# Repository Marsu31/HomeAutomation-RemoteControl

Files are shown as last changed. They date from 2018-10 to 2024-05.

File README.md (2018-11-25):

# HomeAutomation-RemoteControl
MQTT Wifi/BLE Remote control

## Besoin

### Problématique

Les volets roulants électriques sont équipés de modules domotique et s'ouvrent automatiquement au lever du soleil. Pour ce qui est de leur fermeture, le soir, chaque jour est une sitation différente assez imprédictible. L'idée est donc de pouvoir agir avec un moyen simple tel l'appui sur un bouton.
Un bouton 1-Click aurait pu faire l'affaire mais ne présente aucune évolutivité. Une télécommande plus complète permet aussi de se challenger ^^

### Cahier des charges

* **Pratique**
 * **Tenir dans la main**. Pas dans 2 mains, pas dans une main de géant.
 * **Actions rapides**. Par simple appui sur un bouton.
 * **Configurable**. Pour évoluer avec l'équipement de la maison et les besoins qui apparaîtront avec le temps. La saisie doit être ergonomique.
 * **Rechargeable**. Puisque sans fil. Pas sûr que ce soit super écolo mais j'apprendrai ainsi à gérer une batterie.
 * **Sans fil**. Ca semble évident.
 * **Lisible**. Ecran LCD, en relation avec la configurabilité.
 * **Utilisable dès la prise en main**. Ne pas attendre une sortie de veille trop longue.
* **Compatible**. Afin d'être utilisable avec un maximum de systèmes domotiques si jamais nous devions en changer.
* **Consommation réduite**. Pour le &laquo; léger &raquo; côté écolo.

## Conception

### Spécifications techniques

* **Tenir dans la main** : après mesure d'une main on obtient les dimensions L x l x h = 120 x 60 x 40 mm. Il faudrait que l'ensemble rentre dans ce volume.
* **Actions rapides** : 4 boutons poussoir aux couleurs habituelles sur les radiocommandes (rouge, vert, jaune, bleu).
* **Configurable** : encodeur rotatif avec interrupteur afin de naviguer aisément dans un menu, défilement des items sur l'écran LCD.
* **Rechargeable** : via la prise USB du module ESP.
* **Sans fil** : utilisation d'un ESP8266 ou ESP32 pour le Wifi voire le BLE.
* **Lisible** : écran LCD de 1,8".
* **Utilisable dès la prise en main** : capteur de secousse pour la détection.
* **Compatible** : protocole MQTT.
* **Consommation réduite** : mise en veille d'un maximum de composants (ESP, écran).

Utilisation des logiciels suivants :
* conception 3D : FreeCAD
* conception PCB : Fritzing + KiCAD
* préparation de l'impression 3D : Cura

### Maquette

La première étape consiste en la modélisation du volume. Une forme ovoïde semble facile à tenir.

L'écran, l'encodeur, les boutons et le module ESP ont des tailles bien déterminées. Commençons par les positionner.

Ensuite on peut chercher des composants adaptés à l'espace restant. Le plus volumineux d'entre eux est la batterie LiPo. 10 batteries sont étudiées, le modèle de 1200 mAh rentre convenablement sans déborder.

Voici l'esquisse résultant de cette étude :
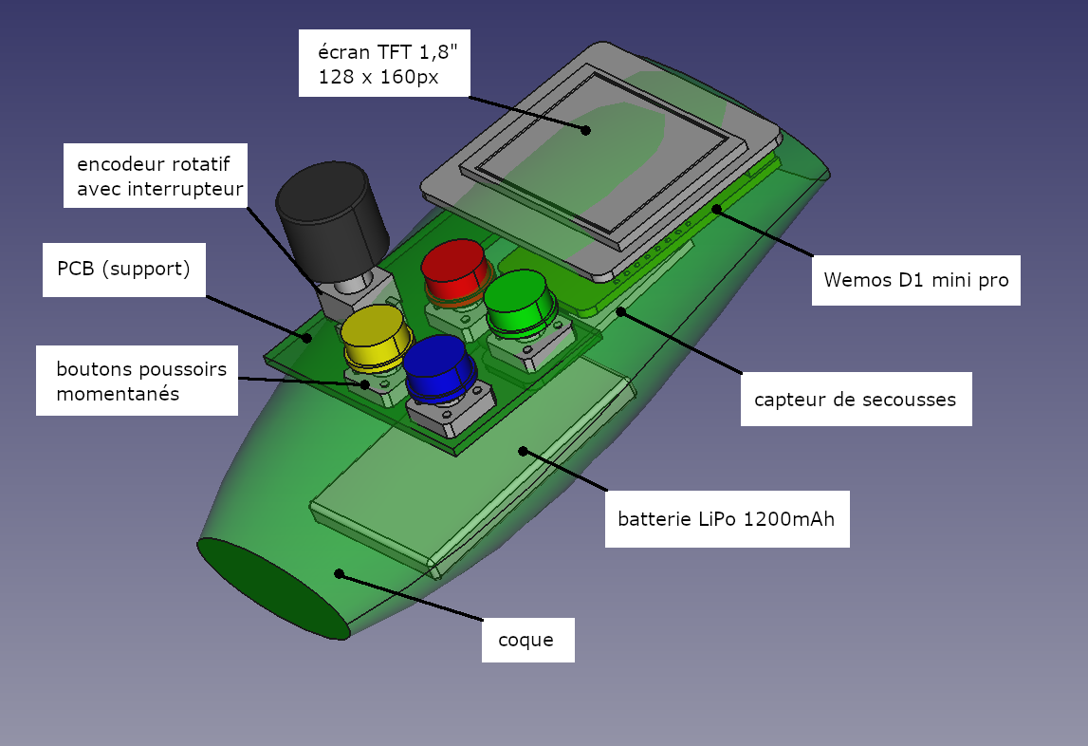
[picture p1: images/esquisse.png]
Esquisse n°1


## Etude en cours

### Composants

 * le réglage du capteur de secousse est difficile. Il y a une bascule rapide lors de la manipulation du potentiomètre (10k&Omega;). Le réglage à peu près correct amène le potard à 2,22V de tension pour 3,3V à ses bornes. Soit environ 3,3k&Omega;/6,7k&Omega; de résistance (vérifier le calcul). Tester avec une résistance de 5,1k&Omega; ou 6,8k&Omega; et un potard de 1k&Omega; ou 2k&Omega; en série pour permettre un réglage plus fin. Utiliser un potard de précision (celui avec une vraie vis).

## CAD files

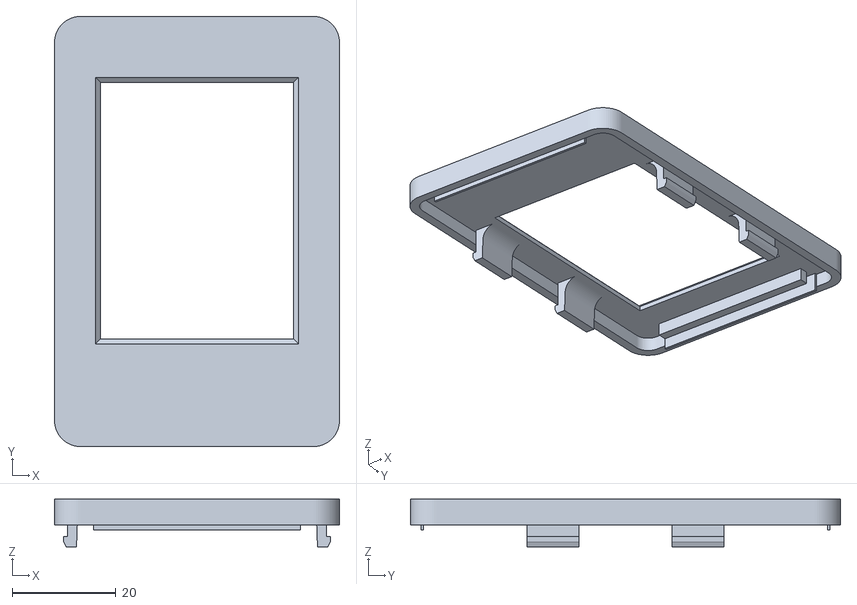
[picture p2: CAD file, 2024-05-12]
freecad/boitier-dessus.stl
55.0 x 83.0 x 9.25

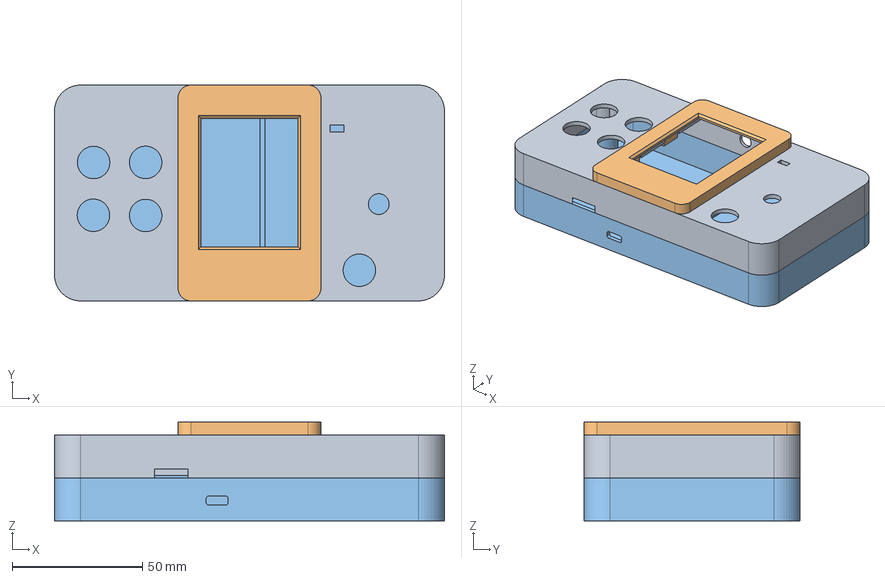
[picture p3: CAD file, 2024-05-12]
freecad/telecommande-model-5.FCStd
150.0 x 83.0 x 38.0 mm
boitier-haut
boitier-dessus
boitier-bas

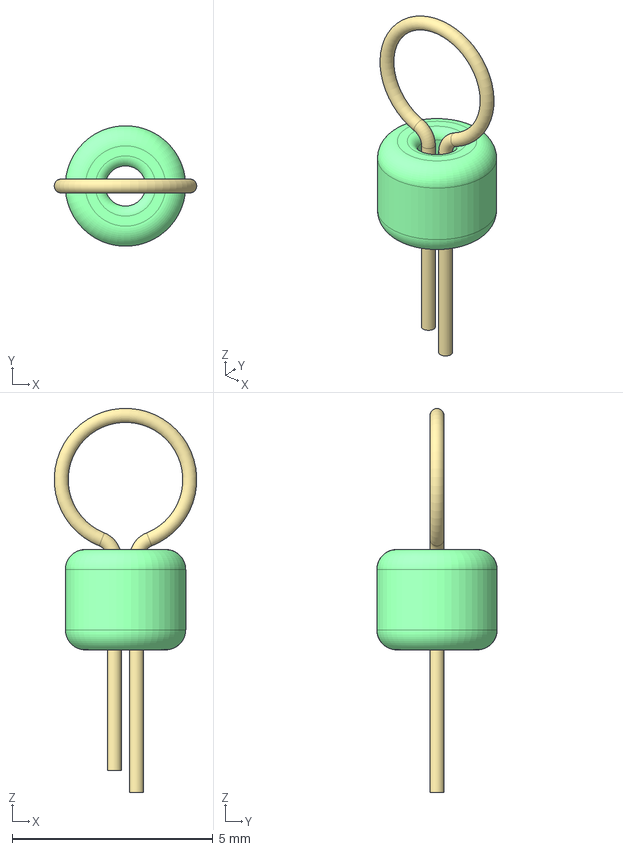
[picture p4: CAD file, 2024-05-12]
freecad/composants.FCStd
3.55 x 3.00 x 9.56 mm
pin
perle_blanc
perle_noir
perle_vert
perle_jaune
perle_rouge
perle_bleu

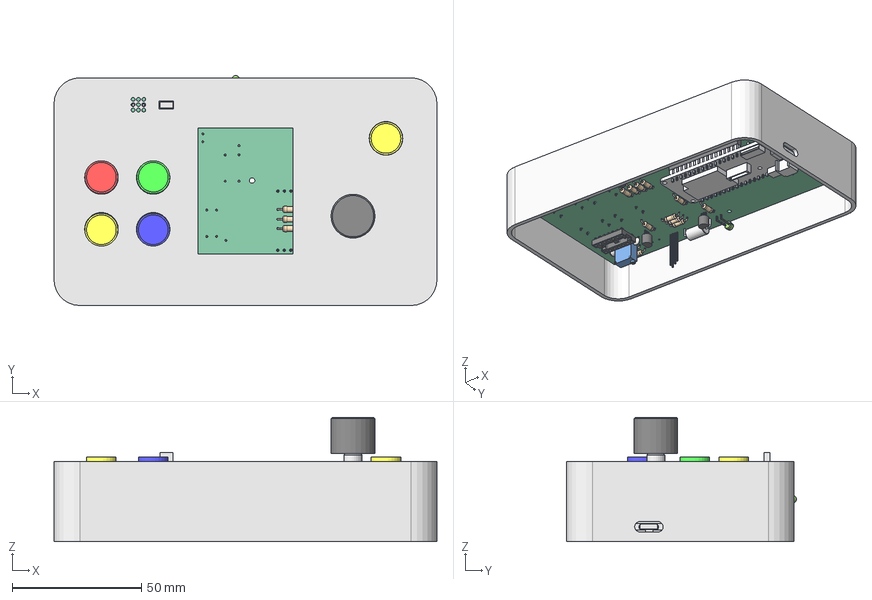
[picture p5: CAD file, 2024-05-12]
freecad/telecommande-model-2.FCStd
148.0 x 88.9 x 48.0 mm
Pcb
led_rgb_rectangle
U3_PinSocket_1x14_P254mm_Vertical_5DE3F0B4
SW6_bouton_poussoir_5DE3EFD7[2]
SW6_chapeau_bouton_poussoir_B_5DE3EFD7[3]
SW5_bouton_poussoir_5DE3EFC0[2]
SW5_chapeau_bouton_poussoir_Y_5DE3EFC0[3]
SW3_bouton_poussoir_5DE3EF8C[2]
SW3_chapeau_bouton_poussoir_R_5DE3EF8C[3]
SW1_bouton_rotatif_5DE3EF4C[2]
SW1_chapeau_bouton_rotatif_5DE3EF4C[3]
SW7_bouton_poussoir_5DE3EFF1[2]
SW7_chapeau_bouton_poussoir_Y_5DE3EFF1[3]
SW4_bouton_poussoir_5DE3EFA6[2]
SW4_chapeau_bouton_poussoir_G_5DE3EFA6[3]
R17_R_Axial_DIN0207_L63mm_D25mm_P1016mm_Horizontal_5DE3EEF5
R7_R_Axial_DIN0207_L63mm_D25mm_P1016mm_Horizontal_5DE3EE0F
R6_R_Axial_DIN0207_L63mm_D25mm_P1016mm_Horizontal_5DE3EDF8
R4_R_Axial_DIN0207_L63mm_D25mm_P1016mm_Horizontal_5DE3EDCA
R18_R_Axial_DIN0207_L63mm_D25mm_P1016mm_Horizontal_5DE4A91E
Q3_TO-92_Inline_Narrow_5DE4A61B
R13_R_Axial_DIN0207_L63mm_D25mm_P1016mm_Horizontal_5DE483DA
R15_R_Axial_DIN0207_L63mm_D25mm_P1016mm_Horizontal_5DE48398
R14_R_Axial_DIN0207_L63mm_D25mm_P1016mm_Horizontal_5DE48356
U4_DIP_14_W762mm_Socket_5DE4B5D4
sw-420_15mm_Horizontal
RV2_Potentiometer_Bourns_3296W_Vertical_5DE3EF32
U2_DIP_8_W762mm_Socket_5DE3F08A
U1_PinSocket_1x16_P254mm_Vertical_5DE3F066
U1_PinSocket_1x16_P254mm_Vertical_5DE3F066[2]
wemos_lolin_d32_pro
R16_R_Axial_DIN0207_L63mm_D25mm_P1016mm_Horizontal_5DE3EEDE
R12_R_Axial_DIN0207_L63mm_D25mm_P1016mm_Horizontal_5DE3EE82
R11_R_Axial_DIN0207_L63mm_D25mm_P1016mm_Horizontal_5DE3EE6B
R10_R_Axial_DIN0207_L63mm_D25mm_P1016mm_Horizontal_5DE3EE54
R9_R_Axial_DIN0207_L63mm_D25mm_P1016mm_Horizontal_5DE3EE3D
R8_R_Axial_DIN0207_L63mm_D25mm_P1016mm_Horizontal_5DE3EE26
R5_R_Axial_DIN0207_L63mm_D25mm_P1016mm_Horizontal_5DE3EDE1
R3_R_Axial_DIN0207_L63mm_D25mm_P1016mm_Horizontal_5DE3EDB3
R2_R_Axial_DIN0207_L63mm_D25mm_P1016mm_Horizontal_5DE47FC9
R1_R_Axial_DIN0207_L63mm_D25mm_P1016mm_Horizontal_5DE48665
Q2_TO-92_Inline_Narrow_5DE3ED6E
Q1_TO-92_Inline_Narrow_5DE3ED5C
D1_LED_D3.0mm_Horizontal_O6.35mm_Z2.0mm_5DE3ED35
C4_C_Disc_D38mm_W26mm_P250mm_5DE4B711
C3_C_Disc_D38mm_W26mm_P250mm_5DE3ECF6
C2_C_Disc_D38mm_W26mm_P250mm_5DE3ECE1
C1_C_Disc_D38mm_W26mm_P250mm_5DE3ECCC

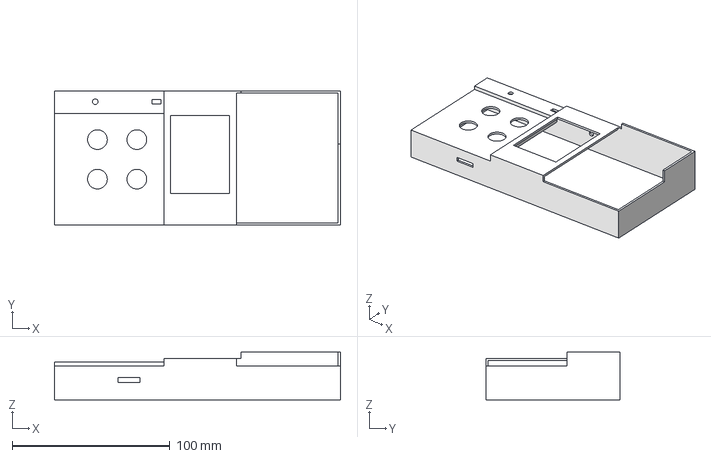
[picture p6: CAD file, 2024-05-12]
freecad/telecommande-model-2b.FCStd
181.4 x 85.3 x 30.2 mm

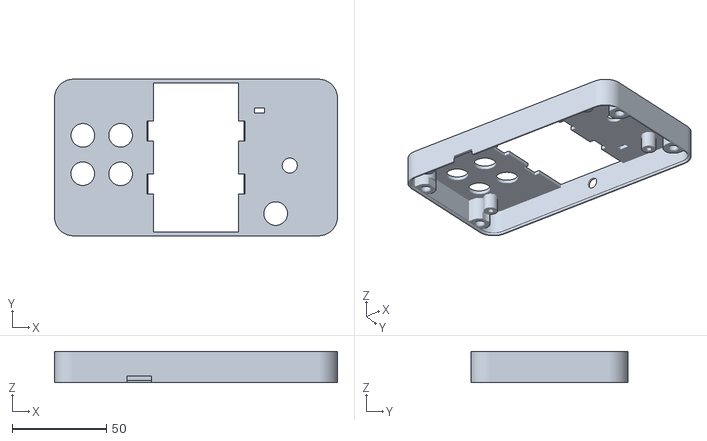
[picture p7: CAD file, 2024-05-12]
freecad/boitier-haut.stl
150.0 x 83.0 x 16.5

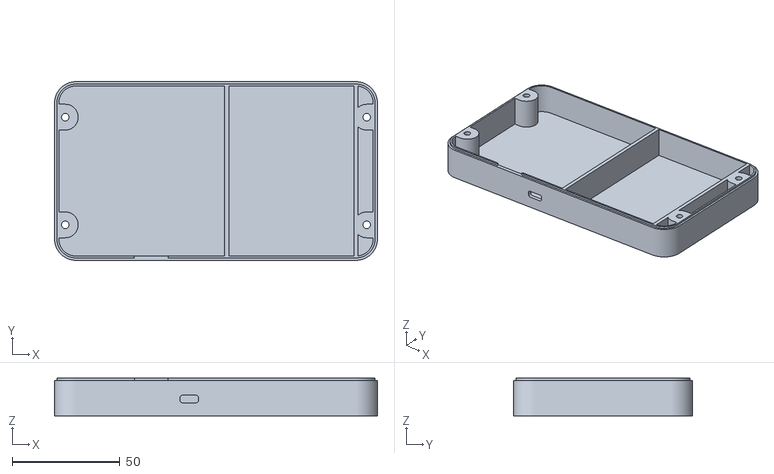
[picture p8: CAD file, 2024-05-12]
freecad/boitier-bas.stl
150.0 x 83.0 x 17.5

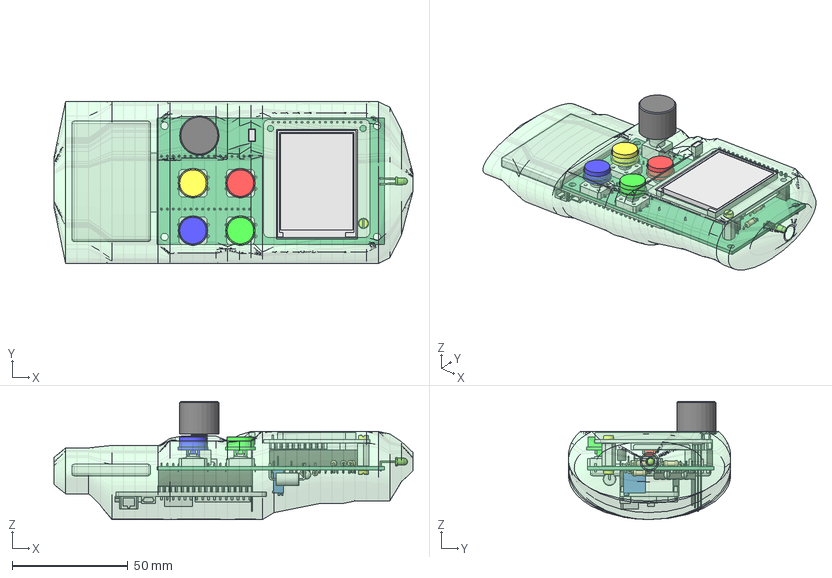
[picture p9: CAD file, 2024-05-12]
freecad/telecommande-model-1b.FCStd
155.0 x 70.0 x 51.0 mm
batterie_1200b-ok
Pcb
R8_R_Axial_DIN0207_L63mm_D25mm_P1016mm_Horizontal_5D49CEC2
D1_LED_D3.0mm_Horizontal_O6.35mm_Z2.0mm_5D49CD43
U2_PinSocket_1x16_P254mm_Vertical_5D49B4B3
U2_tft_1_8in_128x160_5D49B4B3[2]
U2_M2_5x10-Spacer_5D49B4B3[3]
U2_M2.5x5-Screw_5D49B4B3[4]
U2_M2.5x5-Screw_5D49B4B3[5]
D2_led_rgb_rectangle_5D49981D
SW3_bouton_rotatif_5D424077[2]
SW3_chapeau_bouton_rotatif_5D424077[3]
SW1_bouton_poussoir_5D423FEB[2]
SW1_chapeau_bouton_poussoir_R_5D423FEB[3]
SW5_bouton_poussoir_5D4241B3[2]
SW5_chapeau_bouton_poussoir_B_5D4241B3[3]
SW4_bouton_poussoir_5D423DE4[2]
SW4_chapeau_bouton_poussoir_G_5D423DE4[3]
SW2_bouton_poussoir_5D438F57[2]
SW2_chapeau_bouton_poussoir_Y_5D438F57[3]
R2_R_Axial_DIN0207_L63mm_D25mm_P1016mm_Horizontal_5D457423
R1_R_Axial_DIN0207_L63mm_D25mm_P1016mm_Horizontal_5D457B55
R5_R_Axial_DIN0207_L63mm_D25mm_P1016mm_Horizontal_5D49D726
R4_R_Axial_DIN0207_L63mm_D25mm_P1016mm_Horizontal_5D49D69C
R3_R_Axial_DIN0207_L63mm_D25mm_P1016mm_Horizontal_5D49D6DE
Q1_TO-92_Inline_Narrow_5D457382
U1_PinSocket_1x16_P254mm_Vertical_5D46A0D8
U1_PinSocket_1x16_P254mm_Vertical_5D46A0D8[2]
U1_wemos_lolin_d32_pro_5D46A0D8[3]
SW6_sw-420_15mm_Horizontal_5D457563
U3_DIP_14_W762mm_Socket_5D457677
RV1_Potentiometer_Bourns_3296W_Vertical_5D45743A
R7_R_Axial_DIN0207_L63mm_D25mm_P1016mm_Horizontal_5D45B16B
R6_R_Axial_DIN0207_L63mm_D25mm_P1016mm_Horizontal_5D457929
C2_C_Disc_D38mm_W26mm_P250mm_5D457274
C1_C_Disc_D38mm_W26mm_P250mm_5D457C04

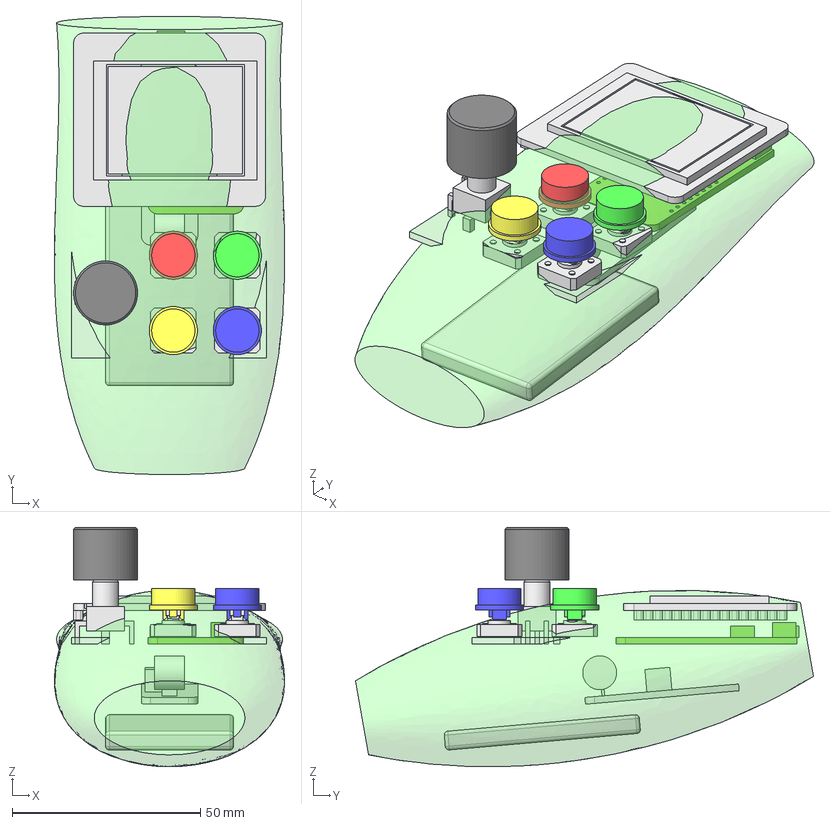
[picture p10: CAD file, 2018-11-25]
freecad/telecommande-model-1.FCStd
61.1 x 121.6 x 63.5 mm
ecran
bouton_rotatif
chapeau_bouton_rotatif
chapeau_bouton_poussoir_R
chapeau_bouton_poussoir_G
chapeau_bouton_poussoir_Y
chapeau_bouton_poussoir_B
bouton_poussoir_R
bouton_poussoir_G
bouton_poussoir_Y
bouton_poussoir_B
weemos_D1_mini_pro
pcb_montage
draft_volume_01
capteur_vibrations
batterie_1200b-ok

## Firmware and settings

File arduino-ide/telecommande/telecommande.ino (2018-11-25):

#include <Arduino.h>
#include <FunctionalInterrupt.h>
#include <driver/dac.h>


// TODO : détecter si câble USB branché
#define DEV

class Button
{
  public:
    Button(uint8_t reqPin) : _pin(reqPin) {
      _pressed = false;
      _nbPressed = 0;
      pinMode(_pin, INPUT_PULLUP);
      attachInterrupt(_pin, std::bind(&Button::isr, this), FALLING);
    };
    ~Button() {
      detachInterrupt(_pin);
    }

    void IRAM_ATTR isr() {
      _pressed = true;
      _nbPressed++;
    }

    bool isPressed() {
      bool pressed = _pressed;
      _pressed = false;
      return pressed;
    }

    uint8_t nbPressed() {
      return _nbPressed;
    }

    void setCallback(void (*callback)(void) ) {
      _callback = callback;
    }

  private:
    const uint8_t _pin;
    volatile bool _pressed;
    volatile uint8_t _nbPressed;
    void (*_callback)(void);
};



#define VOLTAGE_BASE  3.64 // tension de base de la batterie
#define VOLTAGE_INTERVAL 30000 // mesure toutes les X secondes (X x 1000 ms)

static const uint8_t BTN_SLEEP  = 13;
static const uint8_t BTN_RED    = 32;
static const uint8_t BTN_GREEN  = 33;
static const uint8_t BTN_YELLOW = 25;
static const uint8_t BTN_BLUE   = 26;
static const uint8_t BTN_ROTARY = 0;

static const uint8_t LEDRGB_RED_PIN   = A17;
static const uint8_t LEDRGB_GREEN_PIN = A16;
static const uint8_t LEDRGB_BLUE_PIN  = A15;
static const uint8_t LEDRGB_RED_CHANNEL   = 1;
static const uint8_t LEDRGB_GREEN_CHANNEL = 2;
static const uint8_t LEDRGB_BLUE_CHANNEL  = 3;

static const uint8_t SECOUSSE = 34;


// variables d'état
unsigned long voltageLastMeasureMillis = 0;
int btnSleep;
int btnRed;
int btnGreen;
int btnYellow;
int btnBlue;
int btnRotary;


// variables valables sur 1 itération (de loop())
unsigned long currentMillis;

// objets
// boutons de contrôle
Button buttonSleep(BTN_SLEEP);
Button buttonRed(BTN_RED);
Button buttonGreen(BTN_GREEN);
Button buttonYellow(BTN_YELLOW);
Button buttonBlue(BTN_BLUE);
Button buttonRotary(BTN_ROTARY);

volatile int secousseDecalage = 0;
void secousse() {
  for (int i = 0; i < secousseDecalage; i++) {
    Serial.print(F("   "));
  }
  Serial.println(F("¯|_"));
  secousseDecalage = ( secousseDecalage + 1 ) % 10;
}

void setup() {
  Serial.begin(115200);

#ifdef DEV
  delay(1000);
#endif

  dac_output_disable(DAC_CHANNEL_1);
  dac_output_disable(DAC_CHANNEL_2);
  dac_i2s_disable();

  print_wakeup_reason();

  // mesure de la tension (_VBAT = 35)
  pinMode(_VBAT, INPUT);

  // led RGB (TODO : led que si cable usb branché = mode recharge)
  ledcAttachPin(LEDRGB_RED_PIN,   LEDRGB_RED_CHANNEL);
  ledcAttachPin(LEDRGB_GREEN_PIN, LEDRGB_GREEN_CHANNEL);
  ledcAttachPin(LEDRGB_BLUE_PIN,  LEDRGB_BLUE_CHANNEL);
  ledcSetup(LEDRGB_RED_CHANNEL, 12000, 8); // 12 kHz PWM, 8-bit resolution
  ledcSetup(LEDRGB_GREEN_CHANNEL, 12000, 8);
  ledcSetup(LEDRGB_BLUE_CHANNEL, 12000, 8);
  setRGBLedOff();

  // retour de sleep mode      SECOUSSE
//  pinMode(SECOUSSE, INPUT);
//  attachInterrupt(SECOUSSE, secousse, FALLING);

  // bouton rouge
  //  esp_sleep_enable_ext0_wakeup(GPIO_NUM_32, 0);

  // secousse
  esp_sleep_enable_ext0_wakeup(GPIO_NUM_34, 0);

  // bouton rotatif pressé
  //  esp_sleep_enable_ext0_wakeup(GPIO_NUM_0, 0); //1 = High, 0 = Low
}

void loop() {

  currentMillis = millis();

  // --------------------------------------------------------------------------------------------
  //                                           BOUTONS
  // --------------------------------------------------------------------------------------------
  if ( buttonRed.isPressed() ) {
    Serial.print(F("Bouton ROUGE pressé ("));
    Serial.print(buttonRed.nbPressed());
    Serial.println(F(" fois)"));
    setRGBLedColorRed();
  }
  if ( buttonGreen.isPressed() ) {
    Serial.print(F("Bouton VERT pressé ("));
    Serial.print(buttonGreen.nbPressed());
    Serial.println(F(" fois)"));
    setRGBLedColorGreen();
  }
  if ( buttonYellow.isPressed() ) {
    Serial.print(F("Bouton JAUNE pressé ("));
    Serial.print(buttonYellow.nbPressed());
    Serial.println(F(" fois)"));
    setRGBLedColorYellow();
  }
  if ( buttonBlue.isPressed() ) {
    Serial.print(F("Bouton BLEU pressé ("));
    Serial.print(buttonBlue.nbPressed());
    Serial.println(F(" fois)"));
    setRGBLedColorBlue();
  }
  if ( buttonRotary.isPressed() ) {
    Serial.print(F("Bouton ROTATIF pressé ("));
    Serial.print(buttonRotary.nbPressed());
    Serial.println(F(" fois)"));
    setRGBLedColorPurple();
  }
  // --------------------------------------------------------------------------------------------

  // --------------------------------------------------------------------------------------------
  //                                       DEEP SLEEP MANUEL
  // --------------------------------------------------------------------------------------------
  if ( buttonSleep.isPressed() ) {
    Serial.println(F("Bouton BLANC pressé"));
    setRGBLedOff();
//    detachInterrupt(SECOUSSE);

    Serial.println("Going to sleep in 3 seconds...");
    delay(1000);
    Serial.println("Going to sleep in 2 seconds...");
    delay(1000);
    Serial.println("Going to sleep in 1 second...");
    delay(1000);
    Serial.println("Going to sleep NOW !");
    esp_deep_sleep_start();
    Serial.println("This will never be printed");
  }
  // --------------------------------------------------------------------------------------------

  // --------------------------------------------------------------------------------------------
  //                                           VOLTAGE
  // --------------------------------------------------------------------------------------------
  // TODO : remplacer par un timer (callback) ou par une tache FreeRTOS
  // gérer la réinitialisation de millis() au bout de 50j
  if ( currentMillis > ( voltageLastMeasureMillis + VOLTAGE_INTERVAL) || currentMillis < voltageLastMeasureMillis ) {
    voltageLastMeasureMillis = currentMillis;
//        double voltage = getVoltage();
//        printVoltage(voltage);
  }
  // --------------------------------------------------------------------------------------------

  delay(500);

}

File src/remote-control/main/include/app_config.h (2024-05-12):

/*
 * app_config.h
 *
 *  Created on: 13 nov. 2019
 *      Author: gabe
 */

#ifndef MAIN_INCLUDE_APP_CONFIG_H_
#define MAIN_INCLUDE_APP_CONFIG_H_

#include <stdbool.h>
#include "freertos/FreeRTOS.h"
#include "freertos/event_groups.h"
#include "freertos/timers.h"
#include "driver/gpio.h"

// GPIOs

#define GPIO_LEVEL_LOW		0
#define GPIO_LEVEL_HIGH		1

// Buttons (push, rotative)
#define BTN_NUMBER			6 // 6 push button

#define GPIO_BTN_RED		GPIO_NUM_32
#define GPIO_BTN_GREEN     	GPIO_NUM_33
#define GPIO_BTN_YELLOW   	GPIO_NUM_25
#define GPIO_BTN_BLUE     	GPIO_NUM_26
#define GPIO_BTN_ROT     	GPIO_NUM_34
#define GPIO_BTN_ROT_1     	GPIO_NUM_39
#define GPIO_BTN_ROT_2    	GPIO_NUM_36
#define GPIO_BTN_WHITE     	GPIO_NUM_13

// Shake sensor
#define GPIO_SENSOR_SHAKE	GPIO_NUM_15

// Multicolors LED
#define GPIO_LED_MULTI_RED		GPIO_NUM_27
#define GPIO_LED_MULTI_GREEN	GPIO_NUM_14
#define GPIO_LED_MULTI_BLUE		GPIO_NUM_12

// Battery
#define BATTERY_VOLTAGE_MAX		4200	// mV
#define BATTERY_VOLTAGE_ALARM	2500	// mV. Brownout at 2430mV +/- 50mV.

// Sleep
#define INACTIVITY_BEFORE_SLEEP	30000	// millis

typedef struct {
	char *name;
	gpio_num_t gpio_num;
	// can wake up from deep sleep (HIGH level required to wake up <=> active HIGH <=> pulled down)
	bool active_high;
	// debounce
	uint16_t history;
	// event group
	UBaseType_t event_mask;
} button_t;

// button list
button_t *buttons[BTN_NUMBER];

TimerHandle_t xHibernationTimer;

void configure_pin(gpio_num_t gpio_num, bool enablePullup, bool enablePulldown);

#endif /* MAIN_INCLUDE_APP_CONFIG_H_ */

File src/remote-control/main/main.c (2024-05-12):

#include <stdio.h>

#include "freertos/FreeRTOS.h"
#include "freertos/task.h"
#include "freertos/event_groups.h"
#include "esp_log.h"

#include "app_config.h"
#include "battery.h"
#include "buttons.h"
#include "led_multi.h"
#include "screen.h"
#include "shake.h"
#include "sleep.h"

static const char *TAG = "  remote-control"; // ESP_LOG*

void app_main() {

	ESP_LOGI(TAG, "=================================== APP MAIN ===================================");

	// Battery
	ESP_LOGI(TAG, "BATTERY");
	ESP_LOGI(TAG, " - configure battery check");
	init_battery();
	ESP_LOGI(TAG, " - create battery check timer");
	configASSERT(init_battery_check_timer());
// TODO : task/interrupt to check if USB plugged

	// Buttons
	ESP_LOGI(TAG, "BUTTONS");
	ESP_LOGI(TAG, " - create button scan event group");
	init_btn_scan_event_group();
	ESP_LOGI(TAG, " - configure buttons");
	init_buttons();
	ESP_LOGI(TAG, " - create button scan task");
	init_btn_scan_task();
	ESP_LOGI(TAG, " - create button scan hardware timer");
	init_btn_scan_timer();

	// LED multicolor
	ESP_LOGI(TAG, "LED MULTI");
	ESP_LOGI(TAG, " - initialize LED multi (ledc channels)");
	init_led_multi();

	// Shake sensor
	ESP_LOGI(TAG, "SHAKE SENSOR");
	ESP_LOGI(TAG, " - initialize shake sensor");
	init_shake_sensor();
	// TODO : task

	// Hibernation
	ESP_LOGI(TAG, "HIBERNATION");
	ESP_LOGI(TAG, " - initialize hibernation");
	init_hibernation();

	for (;;) {
		vTaskDelay(1000 / portTICK_PERIOD_MS);
	}

}

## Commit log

2018-10-13 version initiale
    [telecommande.FCStd]
2018-11-25 Avancement idées...
    [telecommande.FCStd, telecommande.fzz]
2019-11-16 avancée sur KiCAD
    [RemoteControl.kicad_pcb, RemoteControl.sch]
2019-11-18 multicolor led and sleep mode
2024-05-12 commit de backup
    [RemoteControl.kicad_pcb, RemoteControl.sch, boitier-bas.stl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]
